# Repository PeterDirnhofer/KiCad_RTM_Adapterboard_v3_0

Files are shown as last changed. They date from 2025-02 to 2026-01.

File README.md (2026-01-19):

# 500-rtm-kicad-controllerboard
KiCad files für das Controllerboard des 500Euro Raster Tunnel Mikroskop.
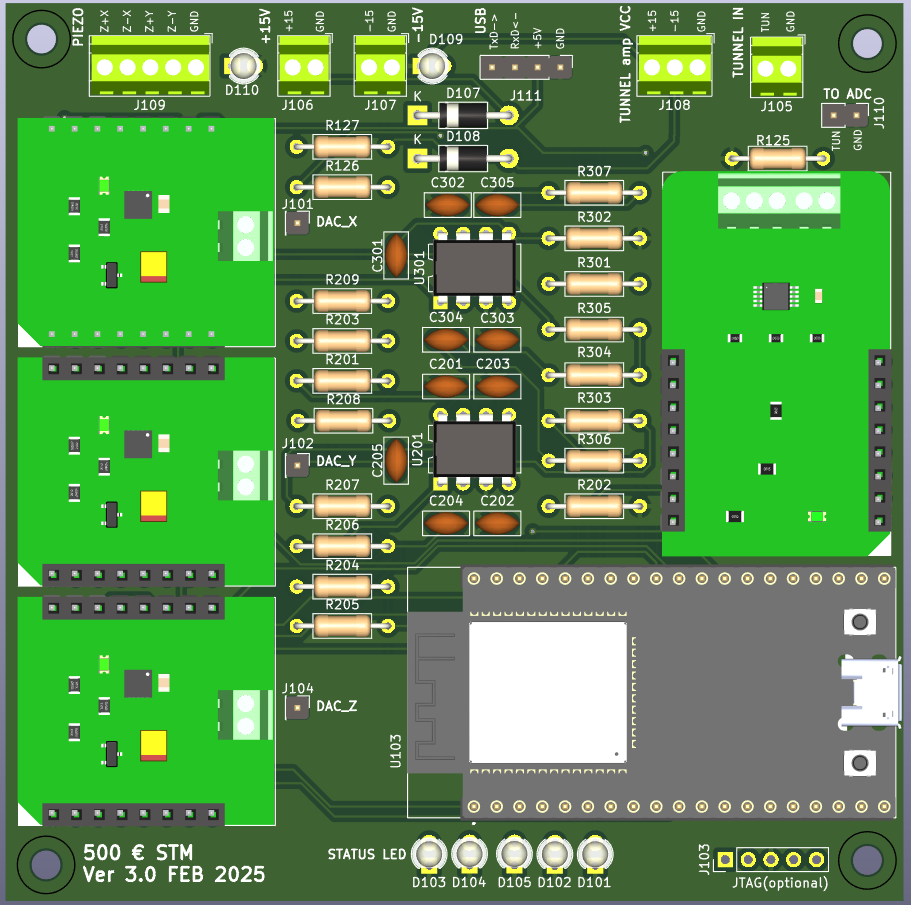
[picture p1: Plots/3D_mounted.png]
Controller board rendering with mounted components
  
  
Beschreibung in https://500-euro-rtm.de/wiki/index.php?title=500-Euro-Rastertunnelmikroskop  

## Patches

<b><h3>3.0.1</h3> (19.01.2026)</b>
- Updated silkscreen description of RX/TX as they were swapped before.  
- Plotted new gerber / drill files and added .zip  
- Updated versioning to 3.0.1 on kicad file  
- Removed versioning from image files to avoid confusion. Also fixed RX/TX there.

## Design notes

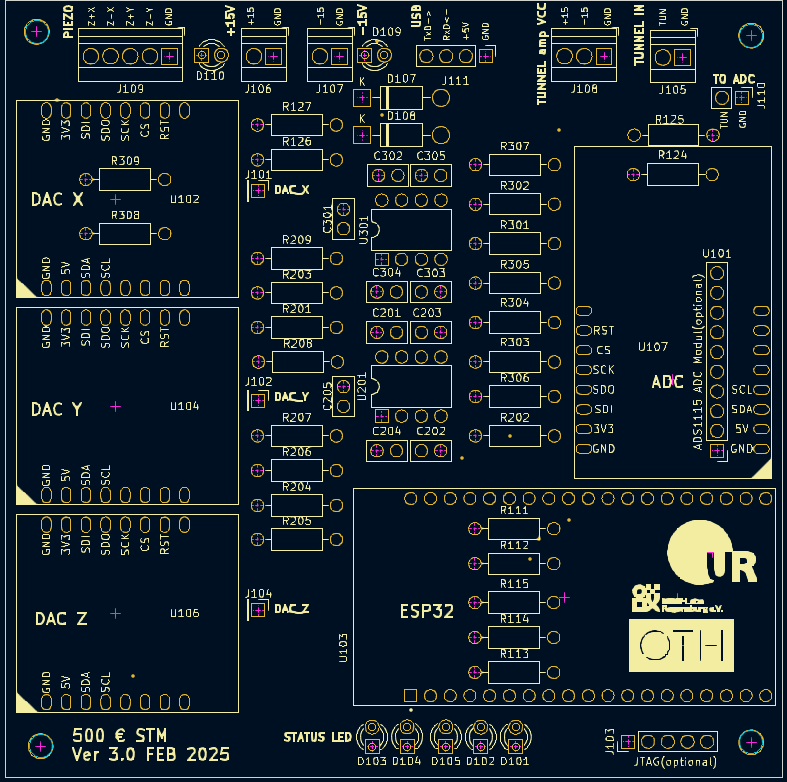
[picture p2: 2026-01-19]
Plots/Silkscreen_Fmask.png

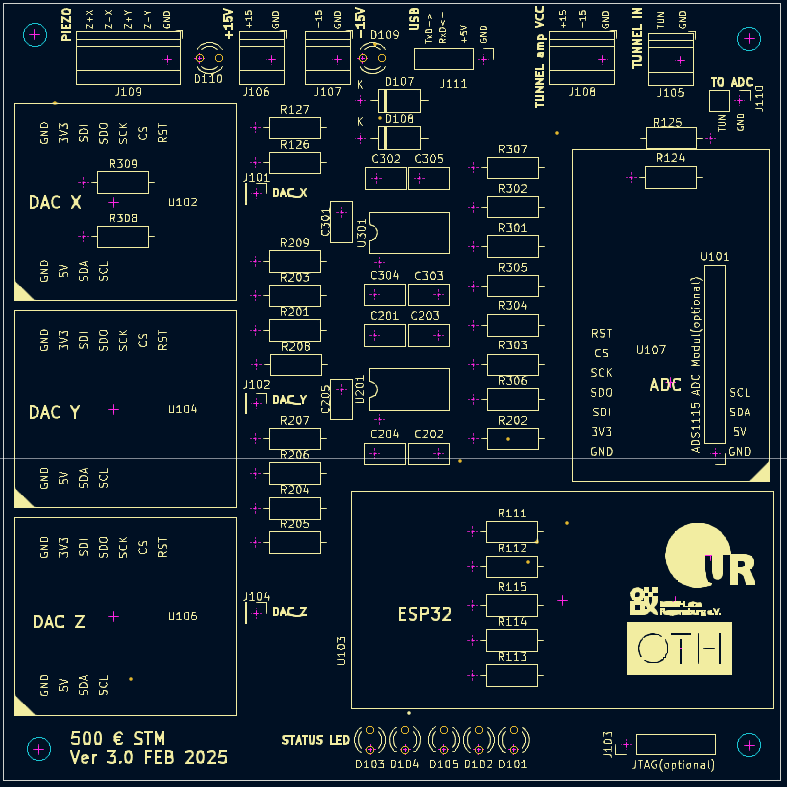
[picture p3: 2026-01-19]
Plots/Silkscreen.png

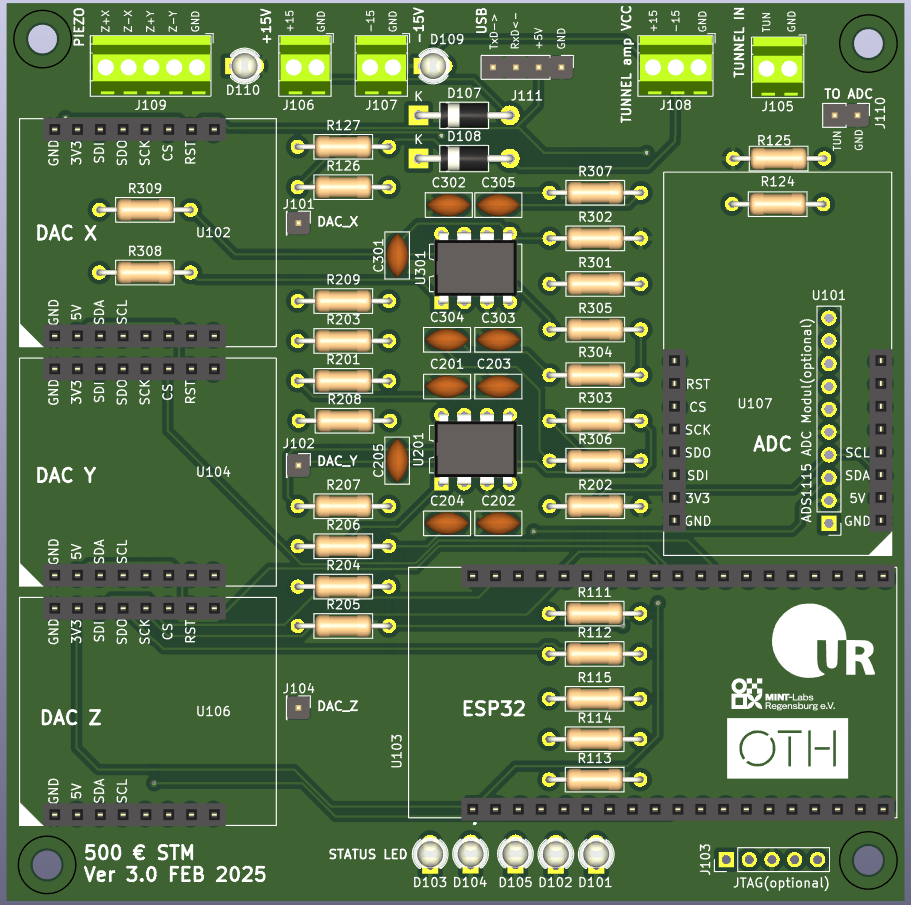
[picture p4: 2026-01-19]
Plots/3D.png

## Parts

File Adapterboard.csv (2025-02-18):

Source: | C:\Users\peter\OneDrive\500_rtm_shared\KiCad_V30\Adapterboard.kicad_sch
Date: | 5/5/2023 11:07:34 AM
Tool: | Eeschema (6.0.10)
Generator: | C:\Program Files\KiCad\6.0\bin\scripting\plugins/bom_csv_grouped_by_value.py
Component Count: | 78
Individual Components:
Item | Qty | Reference(s) | Value | LibPart | Footprint | Datasheet | MANUFACTURER | MAXIMUM_PACKAGE_HEIGHT | PARTREV | SNAPEDA_PN | STANDARD
 |  | C100 | 100n | Device:C_Small | Capacitor_THT:C_Disc_D5.0mm_W2.5mm_P2.50mm | ~
 |  | C101 | 100n | Device:C_Small | Capacitor_THT:C_Disc_D5.0mm_W2.5mm_P2.50mm | ~
 |  | C102 | 4n7 | Device:C | Capacitor_THT:C_Disc_D5.0mm_W2.5mm_P2.50mm | ~
 |  | C103 | 100n | Device:C_Small | Capacitor_THT:C_Disc_D5.0mm_W2.5mm_P2.50mm | ~
 |  | C104 | 100n | Device:C_Small | Capacitor_THT:C_Disc_D5.0mm_W2.5mm_P2.50mm | ~
 |  | C105 | 4n7 | Device:C | Capacitor_THT:C_Disc_D5.0mm_W2.5mm_P2.50mm | ~
 |  | C106 | 4n7 | Device:C | Capacitor_THT:C_Disc_D5.0mm_W2.5mm_P2.50mm | ~
 |  | C107 | 100n | Device:C_Small | Capacitor_THT:C_Disc_D5.0mm_W2.5mm_P2.50mm | ~
 |  | C108 | 4n7 | Device:C | Capacitor_THT:C_Disc_D5.0mm_W2.5mm_P2.50mm | ~
 |  | C109 | 100n | Device:C_Small | Capacitor_THT:C_Disc_D5.0mm_W2.5mm_P2.50mm | ~
 |  | C110 | 4n7 | Device:C | Capacitor_THT:C_Disc_D5.0mm_W2.5mm_P2.50mm | ~
 |  | C111 | 100n | Device:C_Small | Capacitor_THT:C_Disc_D5.0mm_W2.5mm_P2.50mm | ~
 |  | C112 | 4n7 | Device:C | Capacitor_THT:C_Disc_D5.0mm_W2.5mm_P2.50mm | ~
 |  | C113 | 100n | Device:C_Small | Capacitor_THT:C_Disc_D5.0mm_W2.5mm_P2.50mm | ~
 |  | D100 | 1N5819 | Diode:1N5819 | Diode_THT:D_DO-41_SOD81_P10.16mm_Horizontal | http://www.vishay.com/docs/88525/1n5817.pdf
 |  | D101 | 1N5819 | Diode:1N5819 | Diode_THT:D_DO-41_SOD81_P10.16mm_Horizontal | http://www.vishay.com/docs/88525/1n5817.pdf
 |  | D102 | 1N5819 | Diode:1N5819 | Diode_THT:D_DO-41_SOD81_P10.16mm_Horizontal | http://www.vishay.com/docs/88525/1n5817.pdf
 |  | H2 | MountingHole | Mechanical:MountingHole | MountingHole:MountingHole_3.2mm_M3 | ~
 |  | H100 | MountingHole | Mechanical:MountingHole | MountingHole:MountingHole_3.2mm_M3 | ~
 |  | H101 | MountingHole | Mechanical:MountingHole | MountingHole:MountingHole_3.2mm_M3 | ~
 |  | H102 | MountingHole | Mechanical:MountingHole | MountingHole:MountingHole_3.2mm_M3 | ~
 |  | J2 | PotiCenterpin | Connector:Conn_01x01_Female | Adapterboard:Poti_mid_contact | ~
 |  | J3 | PotiCenterpin | Connector:Conn_01x01_Female | Adapterboard:Poti_mid_contact | ~
 |  | J4 | PotiCenterpin | Connector:Conn_01x01_Female | Adapterboard:Poti_mid_contact | ~
 |  | J100 | Y | Connector:Conn_01x01_Female | Connector_PinHeader_2.54mm:PinHeader_1x01_P2.54mm_Vertical | ~
 |  | J101 | X | Connector:Conn_01x01_Female | Connector_PinHeader_2.54mm:PinHeader_1x01_P2.54mm_Vertical | ~
 |  | J102 | Z | Connector:Conn_01x01_Female | Connector_PinHeader_2.54mm:PinHeader_1x01_P2.54mm_Vertical | ~
 |  | J103 | JTAG | Connector:Conn_01x05_Male | Connector_PinHeader_2.54mm:PinHeader_1x05_P2.54mm_Vertical | ~
 |  | J104 | GPIO | Connector_Generic:Conn_02x05_Odd_Even | Connector_PinHeader_2.54mm:PinHeader_2x05_P2.54mm_Vertical | ~
 |  | J107 | POWER | Connector_Generic:Conn_02x05_Odd_Even | Connector_IDC:IDC-Header_2x05_P2.54mm_Vertical | ~
 |  | J108 | STM | Connector_Generic:Conn_02x05_Odd_Even | Connector_PinHeader_2.54mm:PinHeader_2x05_P2.54mm_Vertical | ~
 |  | J109 | TUNNEL_SIGNAL | Connector:Screw_Terminal_01x02 | Connector_PinHeader_2.54mm:PinHeader_1x02_P2.54mm_Vertical | ~
 |  | J110 | ADC input Tunnel | Connector:Conn_01x02_Male | Connector_PinHeader_2.54mm:PinHeader_1x02_P2.54mm_Vertical | ~
 |  | JP101 | SolderJumper_3_Bridged12 | Jumper:SolderJumper_3_Bridged12 | Jumper:SolderJumper-3_P1.3mm_Bridged12_RoundedPad1.0x1.5mm | ~
 |  | R100 | 220 | Device:R | Resistor_THT:R_Axial_DIN0207_L6.3mm_D2.5mm_P10.16mm_Horizontal | ~
 |  | R101 | 3k | Device:R | Resistor_THT:R_Axial_DIN0207_L6.3mm_D2.5mm_P10.16mm_Horizontal | ~
 |  | R102 | 220 | Device:R | Resistor_THT:R_Axial_DIN0207_L6.3mm_D2.5mm_P10.16mm_Horizontal | ~
 |  | R103 | 3k | Device:R | Resistor_THT:R_Axial_DIN0207_L6.3mm_D2.5mm_P10.16mm_Horizontal | ~
 |  | R104 | 3k | Device:R | Resistor_THT:R_Axial_DIN0207_L6.3mm_D2.5mm_P10.16mm_Horizontal | ~
 |  | R105 | 3k | Device:R | Resistor_THT:R_Axial_DIN0207_L6.3mm_D2.5mm_P10.16mm_Horizontal | ~
 |  | R106 | 3k | Device:R | Resistor_THT:R_Axial_DIN0207_L6.3mm_D2.5mm_P10.16mm_Horizontal | ~
 |  | R107 | 3k | Device:R | Resistor_THT:R_Axial_DIN0207_L6.3mm_D2.5mm_P10.16mm_Horizontal | ~
 |  | R108 | 220 | Device:R | Resistor_THT:R_Axial_DIN0207_L6.3mm_D2.5mm_P10.16mm_Horizontal | ~
 |  | R109 | 3k | Device:R | Resistor_THT:R_Axial_DIN0207_L6.3mm_D2.5mm_P10.16mm_Horizontal | ~
 |  | R110 | 3k | Device:R | Resistor_THT:R_Axial_DIN0207_L6.3mm_D2.5mm_P10.16mm_Horizontal | ~
 |  | R111 | 3k | Device:R | Resistor_THT:R_Axial_DIN0207_L6.3mm_D2.5mm_P10.16mm_Horizontal | ~
 |  | R112 | 3k | Device:R | Resistor_THT:R_Axial_DIN0207_L6.3mm_D2.5mm_P10.16mm_Horizontal | ~
 |  | R113 | 3k | Device:R | Resistor_THT:R_Axial_DIN0207_L6.3mm_D2.5mm_P10.16mm_Horizontal | ~
 |  | R114 | 3k | Device:R | Resistor_THT:R_Axial_DIN0207_L6.3mm_D2.5mm_P10.16mm_Horizontal | ~
 |  | R115 | 220 | Device:R | Resistor_THT:R_Axial_DIN0207_L6.3mm_D2.5mm_P10.16mm_Horizontal | ~
 |  | R116 | 3k | Device:R | Resistor_THT:R_Axial_DIN0207_L6.3mm_D2.5mm_P10.16mm_Horizontal | ~
 |  | R117 | 3k | Device:R | Resistor_THT:R_Axial_DIN0207_L6.3mm_D2.5mm_P10.16mm_Horizontal | ~
 |  | R118 | 3k | Device:R | Resistor_THT:R_Axial_DIN0207_L6.3mm_D2.5mm_P10.16mm_Horizontal | ~
 |  | R119 | 1k | Device:R | Resistor_THT:R_Axial_DIN0207_L6.3mm_D2.5mm_P10.16mm_Horizontal | ~
 |  | R120 | 3k | Device:R | Resistor_THT:R_Axial_DIN0207_L6.3mm_D2.5mm_P10.16mm_Horizontal | ~
 |  | R121 | 470 | Device:R | Resistor_THT:R_Axial_DIN0207_L6.3mm_D2.5mm_P10.16mm_Horizontal | ~
 |  | R122 | 10k | Device:R | Resistor_THT:R_Axial_DIN0207_L6.3mm_D2.5mm_P10.16mm_Horizontal | ~
 |  | R123 | 470 | Device:R | Resistor_THT:R_Axial_DIN0207_L6.3mm_D2.5mm_P10.16mm_Horizontal | ~
 |  | R124 | 68k | Device:R | Resistor_THT:R_Axial_DIN0207_L6.3mm_D2.5mm_P10.16mm_Horizontal | ~
 |  | R125 | 1k | Device:R | Resistor_THT:R_Axial_DIN0207_L6.3mm_D2.5mm_P10.16mm_Horizontal | ~
 |  | R126 | 470 | Device:R | Resistor_THT:R_Axial_DIN0207_L6.3mm_D2.5mm_P10.16mm_Horizontal | ~
 |  | R127 | 68k | Device:R | Resistor_THT:R_Axial_DIN0207_L6.3mm_D2.5mm_P10.16mm_Horizontal | ~
 |  | R128 | 1k | Device:R | Resistor_THT:R_Axial_DIN0207_L6.3mm_D2.5mm_P10.16mm_Horizontal | ~
 |  | R129 | 1k | Device:R | Resistor_THT:R_Axial_DIN0207_L6.3mm_D2.5mm_P10.16mm_Horizontal | ~
 |  | U2 | mint | mint:mint | Adapterboard:mint
 |  | U3 | OTH | OTH:OTH | Adapterboard:oth
 |  | U4 | UniRegensburg | UniRegensburg:UniRegensburg | Adapterboard:ur
 |  | U10 | ADC TUNNEL | :Mikroe-Socket_3 | Mikroe:Mikroe_Socket
 |  | U100 | DAC Z | mikroe:Mikroe-Socket | Mikroe:Mikroe_Socket
 |  | U101 | DAC X | :Mikroe-Socket_1 | Mikroe:Mikroe_Socket
 |  | U102 | DAC Z | mikroe:Mikroe-Socket | Mikroe:Mikroe_Socket
 |  | U103 | OPA227P | 2023-02-22_17-26-47:OPA227P | Package_DIP:DIP-8_W7.62mm
 |  | U104 | OPA227P | 2023-02-22_17-26-47:OPA227P | Package_DIP:DIP-8_W7.62mm
 |  | U105 | OPA227P | 2023-02-22_17-26-47:OPA227P | Package_DIP:DIP-8_W7.62mm
 |  | U106 | OPA227P | 2023-02-22_17-26-47:OPA227P | Package_DIP:DIP-8_W7.62mm
 |  | U107 | ESP32-DEVKITC-32D | ESP32-DEVKITC-32D:ESP32-DEVKITC-32D | ESP32-DEVKITC-32D:MODULE_ESP32-DEVKITC-32D |  | Espressif Systems | N/A | V4 | ESP32-DEVKITC-32D | Manufacturer Recommendations
 |  | U108 | USB | CP2102_USB:CP_2102_USB | CP2102_USB:CP2102_USB
 |  | U109 | USB_GENERIC | CP2102_USB:CP_2102_USB_GENERIC | Connector_PinSocket_2.54mm:PinSocket_1x06_P2.54mm_Vertical
Collated Components:
Item | Qty | Reference(s) | Value | LibPart | Footprint | Datasheet | MANUFACTURER | MAXIMUM_PACKAGE_HEIGHT | PARTREV | SNAPEDA_PN | STANDARD
1 | 8 | C100, C101, C103, C104, C107, C109, C111, C113 | 100n | Device:C_Small | Capacitor_THT:C_Disc_D5.0mm_W2.5mm_P2.50mm | ~
2 | 6 | C102, C105, C106, C108, C110, C112 | 4n7 | Device:C | Capacitor_THT:C_Disc_D5.0mm_W2.5mm_P2.50mm | ~
3 | 3 | D100, D101, D102 | 1N5819 | Diode:1N5819 | Diode_THT:D_DO-41_SOD81_P10.16mm_Horizontal | http://www.vishay.com/docs/88525/1n5817.pdf
4 | 4 | H2, H100, H101, H102 | MountingHole | Mechanical:MountingHole | MountingHole:MountingHole_3.2mm_M3 | ~
5 | 3 | J2, J3, J4 | PotiCenterpin | Connector:Conn_01x01_Female | Adapterboard:Poti_mid_contact | ~
6 | 1 | J100 | Y | Connector:Conn_01x01_Female | Connector_PinHeader_2.54mm:PinHeader_1x01_P2.54mm_Vertical | ~
7 | 1 | J101 | X | Connector:Conn_01x01_Female | Connector_PinHeader_2.54mm:PinHeader_1x01_P2.54mm_Vertical | ~
8 | 1 | J102 | Z | Connector:Conn_01x01_Female | Connector_PinHeader_2.54mm:PinHeader_1x01_P2.54mm_Vertical | ~
9 | 1 | J103 | JTAG | Connector:Conn_01x05_Male | Connector_PinHeader_2.54mm:PinHeader_1x05_P2.54mm_Vertical | ~
10 | 1 | J104 | GPIO | Connector_Generic:Conn_02x05_Odd_Even | Connector_PinHeader_2.54mm:PinHeader_2x05_P2.54mm_Vertical | ~
11 | 1 | J107 | POWER | Connector_Generic:Conn_02x05_Odd_Even | Connector_IDC:IDC-Header_2x05_P2.54mm_Vertical | ~
12 | 1 | J108 | STM | Connector_Generic:Conn_02x05_Odd_Even | Connector_PinHeader_2.54mm:PinHeader_2x05_P2.54mm_Vertical | ~
13 | 1 | J109 | TUNNEL_SIGNAL | Connector:Screw_Terminal_01x02 | Connector_PinHeader_2.54mm:PinHeader_1x02_P2.54mm_Vertical | ~
14 | 1 | J110 | ADC input Tunnel | Connector:Conn_01x02_Male | Connector_PinHeader_2.54mm:PinHeader_1x02_P2.54mm_Vertical | ~
15 | 1 | JP101 | SolderJumper_3_Bridged12 | Jumper:SolderJumper_3_Bridged12 | Jumper:SolderJumper-3_P1.3mm_Bridged12_RoundedPad1.0x1.5mm | ~
16 | 4 | R100, R102, R108, R115 | 220 | Device:R | Resistor_THT:R_Axial_DIN0207_L6.3mm_D2.5mm_P10.16mm_Horizontal | ~
17 | 16 | R101, R103, R104, R105, R106, R107, R109, R110, R111, R112, R113, R114, R116, R117, R118, R120 | 3k | Device:R | Resistor_THT:R_Axial_DIN0207_L6.3mm_D2.5mm_P10.16mm_Horizontal | ~
18 | 4 | R119, R125, R128, R129 | 1k | Device:R | Resistor_THT:R_Axial_DIN0207_L6.3mm_D2.5mm_P10.16mm_Horizontal | ~
19 | 3 | R121, R123, R126 | 470 | Device:R | Resistor_THT:R_Axial_DIN0207_L6.3mm_D2.5mm_P10.16mm_Horizontal | ~
20 | 1 | R122 | 10k | Device:R | Resistor_THT:R_Axial_DIN0207_L6.3mm_D2.5mm_P10.16mm_Horizontal | ~
21 | 2 | R124, R127 | 68k | Device:R | Resistor_THT:R_Axial_DIN0207_L6.3mm_D2.5mm_P10.16mm_Horizontal | ~
22 | 1 | U2 | mint | mint:mint | Adapterboard:mint
23 | 1 | U3 | OTH | OTH:OTH | Adapterboard:oth
24 | 1 | U4 | UniRegensburg | UniRegensburg:UniRegensburg | Adapterboard:ur
25 | 1 | U10 | ADC TUNNEL | :Mikroe-Socket_3 | Mikroe:Mikroe_Socket
26 | 2 | U100, U102 | DAC Z | mikroe:Mikroe-Socket | Mikroe:Mikroe_Socket
27 | 1 | U101 | DAC X | :Mikroe-Socket_1 | Mikroe:Mikroe_Socket
28 | 4 | U103, U104, U105, U106 | OPA227P | 2023-02-22_17-26-47:OPA227P | Package_DIP:DIP-8_W7.62mm
29 | 1 | U107 | ESP32-DEVKITC-32D | ESP32-DEVKITC-32D:ESP32-DEVKITC-32D | ESP32-DEVKITC-32D:MODULE_ESP32-DEVKITC-32D |  | Espressif Systems | N/A | V4 | ESP32-DEVKITC-32D | Manufacturer Recommendations
30 | 1 | U108 | USB | CP2102_USB:CP_2102_USB | CP2102_USB:CP2102_USB
31 | 1 | U109 | USB_GENERIC | CP2102_USB:CP_2102_USB_GENERIC | Connector_PinSocket_2.54mm:PinSocket_1x06_P2.54mm_Vertical

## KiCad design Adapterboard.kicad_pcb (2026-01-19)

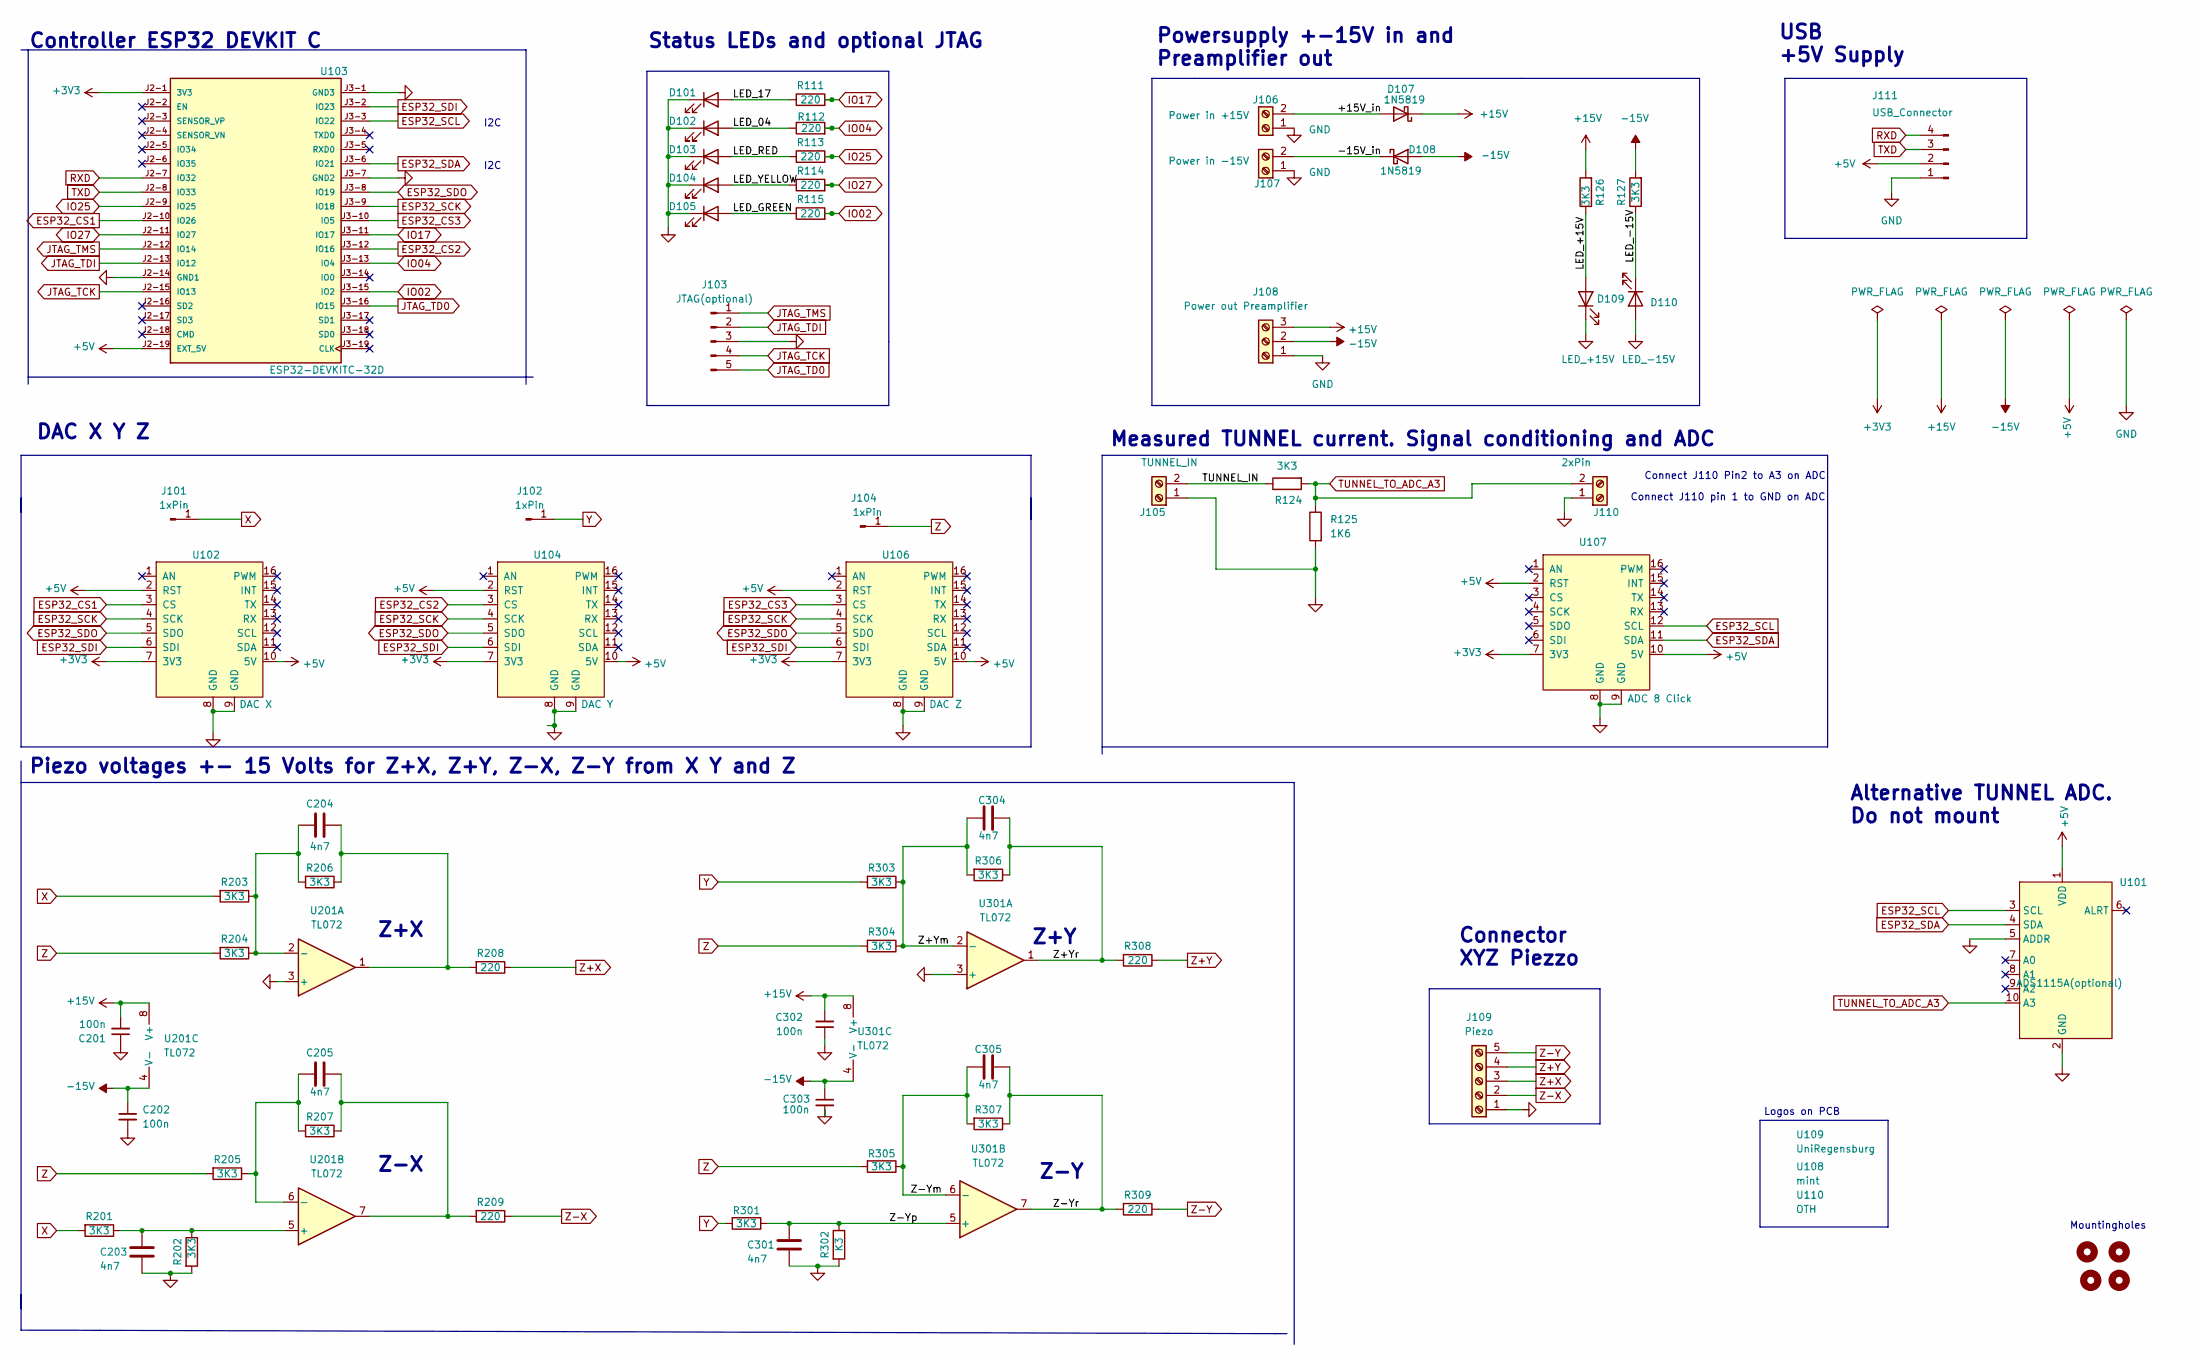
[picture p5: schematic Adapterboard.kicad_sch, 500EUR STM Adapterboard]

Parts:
C201, C202, C302, C303: 100n; C_Disc_D5.0mm_W2.5mm_P2.50mm
C203, C204, C205, C301, C304, C305: 4n7; C_Disc_D5.0mm_W2.5mm_P2.50mm
D101, D102: LED; LED_D3.0mm_Clear
D103: RED; LED_D3.0mm_Clear
D104: YELLOW; LED_D3.0mm_Clear
D105: GREEN; LED_D3.0mm_Clear
D107, D108: 1N5819; D_DO-41_SOD81_P10.16mm_Horizontal
D109: LED_+15V; LED_D3.0mm_Clear
D110: LED_-15V; LED_D3.0mm_Clear
H101, H102, H103, H104: MountingHole; MountingHole_3.2mm_M3
J101, J102, J104: 1xPin; PinHeader_1x01_P2.54mm_Vertical
J103: JTAG(optional); PinHeader_1x05_P2.54mm_Vertical
J105: TUNNEL_IN; TerminalBlock_Xinya_XY308-2.54-2P_1x02_P2.54mm_Horizontal
J106: Power in +15V; TerminalBlock_Xinya_XY308-2.54-2P_1x02_P2.54mm_Horizontal
J107: Power in -15V; TerminalBlock_Xinya_XY308-2.54-2P_1x02_P2.54mm_Horizontal
J108: Power out Preamplifier; TerminalBlock_Xinya_XY308-2.54-3P_1x03_P2.54mm_Horizontal
J109: Piezo; TerminalBlock_Xinya_XY308-2.54-5P_1x05_P2.54mm_Horizontal
J110: 2xPin; PinHeader_1x02_P2.54mm_Vertical
J111: USB_Connector; PinHeader_1x04_P2.54mm_Vertical
R111, R112, R113, R114, R115, R208, R209, R308, R309: 220; R_Axial_DIN0207_L6.3mm_D2.5mm_P10.16mm_Horizontal
R124, R126, R127, R201, R202, R203, R204, R205, R206, R207, R301, R303, R304, R305, R306, R307: 3K3; R_Axial_DIN0207_L6.3mm_D2.5mm_P10.16mm_Horizontal
R125: 1K6; R_Axial_DIN0207_L6.3mm_D2.5mm_P10.16mm_Horizontal
R302: K3; R_Axial_DIN0207_L6.3mm_D2.5mm_P10.16mm_Horizontal
U101: ADS1115A(optional); PinHeader_1x10_P2.54mm_Vertical
U102: DAC X; Mikroe_Socket_DAC_2_Click
U103: ESP32-DEVKITC-32D; MODULE_ESP32-DEVKITC-32D; PARTREV V4
U104: DAC Y; Mikroe_Socket_DAC_2_Click
U106: DAC Z; Mikroe_Socket_DAC_2_Click
U107: ADC 8 Click; Mikroe_Socket_ADC_8_Click
U108: mint
U109: UniRegensburg; ur
U110: OTH; oth
U201, U301: TL072; DIP-8_W7.62mm

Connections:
+3V3: U102.7 (3V3), U103.J2-1 (3V3), U104.7 (3V3), U106.7 (3V3), U107.7 (3V3)
+5V: J111.2, U101.1 (VDD), U102.2 (RST), U102.10 (5V), U103.J2-19 (EXT_5V), U104.2 (RST), U104.10 (5V), U106.2 (RST), U106.10 (5V), U107.2 (RST), U107.10 (5V)
+15V: C201.2, C302.2, D107.1 (K), J108.3, R126.2, U201.8 (V+), U301.8 (V+)
-15V: C202.1, C303.1, D108.2 (A), J108.2, R127.2, U201.4 (V-), U301.4 (V-)
/+15V_in: D107.2 (A), J106.2
/-15V_in: D108.1 (K), J107.2
/LED_04: D102.2 (A), R112.1
/LED_17: D101.2 (A), R111.1
/LED_+15V: D109.2 (A), R126.1
/LED_-15V: D110.1 (K), R127.1
/LED_GREEN: D105.2 (A), R115.1
/LED_RED: D103.2 (A), R113.1
/LED_YELLOW: D104.2 (A), R114.1
/TUNNEL_IN: J105.2, R124.1
/Z+Ym: C304.2, R303.1, R304.1, R306.2, U301.2 (-)
/Z+Yr: C304.1, R306.1, R308.2, U301.1
/Z-Ym: C305.2, R305.1, R307.2, U301.6 (-)
/Z-Yp: C301.1, R301.1, R302.1, U301.5 (+)
/Z-Yr: C305.1, R307.1, R309.2, U301.7
ESP32_CS1: U102.3 (CS), U103.J2-10 (IO26)
ESP32_CS2: U103.J3-12 (IO16), U104.3 (CS)
ESP32_CS3: U103.J3-10 (IO5), U106.3 (CS)
ESP32_SCK: U102.4 (SCK), U103.J3-9 (IO18), U104.4 (SCK), U106.4 (SCK)
ESP32_SCL: U101.3 (SCL), U103.J3-3 (IO22), U107.12 (SCL)
ESP32_SDA: U101.4 (SDA), U103.J3-6 (IO21), U107.11 (SDA)
ESP32_SDI: U102.6 (SDI), U103.J3-2 (IO23), U104.6 (SDI), U106.6 (SDI)
ESP32_SDO: U102.5 (SDO), U103.J3-8 (IO19), U104.5 (SDO), U106.5 (SDO)
GND: C201.1, C202.2, C203.2, C301.2, C302.1, C303.2, D101.1 (K), D102.1 (K), D103.1 (K), D104.1 (K), D105.1 (K), D109.1 (K), D110.2 (A), J103.3, J105.1, J106.1, J107.1, J108.1, J109.1, J110.1, J111.1, R125.2, R202.2, R302.2, U101.2 (GND), U101.5 (ADDR), U102.8 (GND), U102.9 (GND), U103.J2-14 (GND1), U103.J3-1 (GND3), U103.J3-7 (GND2), U104.8 (GND), U104.9 (GND), U106.8 (GND), U106.9 (GND), U107.8 (GND), U107.9 (GND), U201.3 (+), U301.3 (+)
IO02: R115.2, U103.J3-15 (IO2)
IO04: R112.2, U103.J3-13 (IO4)
IO17: R111.2, U103.J3-11 (IO17)
IO25: R113.2, U103.J2-9 (IO25)
IO27: R114.2, U103.J2-11 (IO27)
JTAG_TCK: J103.4, U103.J2-15 (IO13)
JTAG_TD0: J103.5, U103.J3-16 (IO15)
JTAG_TDI: J103.2, U103.J2-13 (IO12)
JTAG_TMS: J103.1, U103.J2-12 (IO14)
unnamed: C204.1, R206.1, R208.2, U201.1
unnamed: C205.1, R207.1, R209.2, U201.7
unnamed: C204.2, R203.1, R204.1, R206.2, U201.2 (-)
unnamed: C203.1, R201.1, R202.1, U201.5 (+)
unnamed: C205.2, R205.1, R207.2, U201.6 (-)
RXD: J111.4, U103.J2-7 (IO32)
TUNNEL_TO_ADC_A3: J110.2, R124.2, R125.1, U101.10 (A3)
TXD: J111.3, U103.J2-8 (IO33)
X: J101.1, R201.2, R203.2
Y: J102.1, R301.2, R303.2
Z: J104.1, R204.2, R205.2, R304.2, R305.2
Z+X: J109.3, R208.1
Z+Y: J109.4, R308.1
Z-X: J109.2, R209.1
Z-Y: J109.5, R309.1

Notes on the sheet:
Measured TUNNEL current. Signal conditioning and ADC
Connector XYZ Piezzo
Status LEDs and optional JTAG
I2C
Z-Y
USB +5V Supply
Powersupply +-15V in and Preamplifier out
Controller ESP32 DEVKIT C
Connect J110 pin 1 to GND on ADC
Mountingholes
Piezo voltages +- 15 Volts for Z+X, Z+Y, Z-X, Z-Y from X Y and Z
Connect J110 Pin2 to A3 on ADC
Logos on PCB
DAC X Y Z
Alternative TUNNEL ADC. Do not mount
Z-X
Z+X
Z+Y

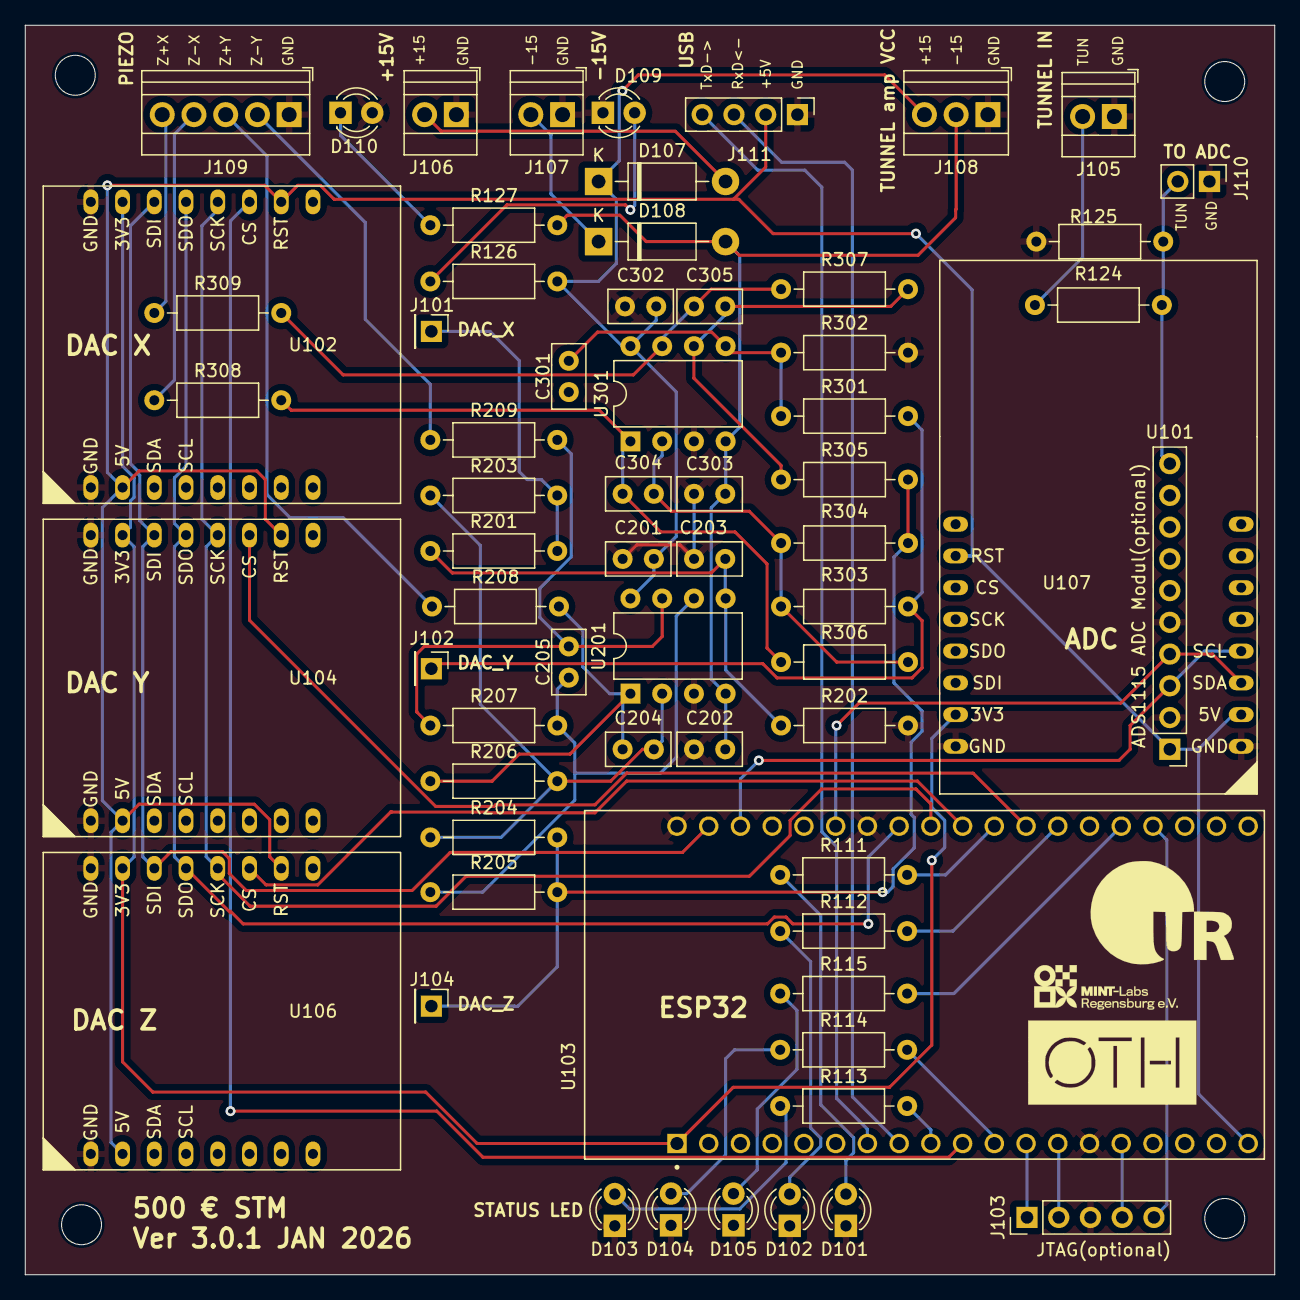
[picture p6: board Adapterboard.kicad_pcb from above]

Board: 2 copper layers, 100.0 x 100.0 mm, 72 parts (0 on the bottom side), 52 nets.

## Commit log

2025-02-18 Initial commit of KiCad project
    [Adapterboard-B_Cu.gbr, Adapterboard-B_Mask.gbr, Adapterboard-B_Paste.gbr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]
2025-02-18 pcb ready. add gnd
    [Adapterboard.kicad_pcb, Adapterboard.kicad_sch]
2025-02-20 Bestellung Fischer 20250220
    [Adapterboard-B_Cu.gbr, Adapterboard-B_Mask.gbr, Adapterboard-B_Paste.gbr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]
2026-01-19 Rx and Tx have been swapped. New Gerber files have been generated. Version number updated to 3.0.1 on gerber silkscreen file
    [Adapterboard-B_Cu.gbr, Adapterboard-B_Mask.gbr, Adapterboard-Edge_Cuts.gbr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]
2026-01-19 Added backup folder from 3.0. Added gerber files
    [Adapterboard-B_Courtyard.gbr, Adapterboard-B_Cu.gbr, Adapterboard-B_Fab.gbr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]
2026-01-19 Updated kicad_pcb file.
    [Adapterboard.kicad_pcb]
